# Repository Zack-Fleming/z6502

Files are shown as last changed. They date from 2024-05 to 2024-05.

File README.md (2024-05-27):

#Z6502

This is a collection of PCBs for a 6502-based computer. The core design of the computer is based on Ben Eater's design [here](https://eater.net/6502). I will be implementing changed to the original changes in the form of version revisions. Each board revision will have its own in-depth README.md, that will go over the changes in more depth and provide other relevant information.

This project was made using the KiCAD software, that can be downloaded [here](https://www.kicad.org/download/). If you do not have KiCAD, then there is also a zip file of the Gerber and Drill files needed to order a PCB. This zip file can be uploaded to any PCB manufacturer with no problem. 

Below the use of pinheaders is mentioned on different occasions, all of these pinheaders are of the 2.54mm pitch variety, and are the same used in the Arduino or Raspberry Pi boards as well. 

## Project Use

Use of this project is encouraged, as this is 'open-source'. I just ask to give credit to this project. 

I would like to know what others create for this project. 

## Revisions at a Glance

Revision V1:

The main changes of this version are the addition of data and control bus readouts, in the form of LEDs and pinheaders. Another change was to add PCB footprins for DIP-8 and DIP-14 type oscillators.

Currently planed Revisions:
- v2: adding a clock switching, clock dividing, halt switch, and power switch
- v3: adding another VIA chip (adding two more I/O ports)
- v4: removing the bus readouts, for miniaturization

## Modules

The computer features two 8-bit ports, that have their own headers for I/O modules. The silkscreen of the board will include all of the information for the design of the modules. This information includes: the position and size of the mounting holes, the length and width of the boards, and the position of the interface pin header. Both I/O ports are situated next to each other, and are identical in dimensions. If an I/O device needs to use both of the available ports, then one can just design a board that combines the two ports into a single board. There is no need to keep the device to only one port. 

I am currently working on a template project for KiCAD, where you can create a project from the template, instead of copy pasting the project multiple times.

Currently planed modules include:
- 1602A 16x2 character LCD screen
- 8x8 button matrix 'keyboard'
- clock switching (not an I/O module)
- LED matrix ??x??
- more.

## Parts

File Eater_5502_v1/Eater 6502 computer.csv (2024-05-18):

Id | Designator | Footprint | Quantity | Designation | Supplier and ref
1 | J5 | PinHeader_1x08_P2.54mm_Vertical | 1 | DATA_CONN
2 | C12,C11,C7,C9,C8,C10 | C_Disc_D5.0mm_W2.5mm_P2.50mm | 6 | 100n
3 | Y1 | Crystal_HC49-4H_Vertical | 1 | 1.84Mhz
4 | R13,R18,R33,R30,R24,R26,R16,R28,R8,R31,R19,R22,R14,R34,R21,R25,R11,R17,R20,R15,R23,R29,R12,R7,R5,R6,R4,R10,R32,R27,R9 | R_Axial_DIN0207_L6.3mm_D2.5mm_P2.54mm_Vertical | 31 | R
5 | U7 | DIP-14_W7.62mm_Socket_LongPads | 1 | 74HC00
6 | D5,D32,D27,D15,D26,D33,D4,D7,D25,D31,D18,D19,D24,D8,D28,D11,D10,D20,D12,D14,D9,D13,D30,D6,D29,D22,D3,D17,D16,D23,D21 | LED_D5.0mm | 31 | LED
7 | J6 | PinHeader_1x04_P2.54mm_Vertical | 1 | CPU_CONN
8 | R1,R2 | R_Axial_DIN0207_L6.3mm_D2.5mm_P2.54mm_Vertical | 2 | 1k
9 | C1 | C_Disc_D5.0mm_W2.5mm_P2.50mm | 1 | .1uF
10 | D2,D1 | D_DO-41_SOD81_P10.16mm_Horizontal | 2 | SB140
11 | U4 | DIP-40_W15.24mm_Socket_LongPads | 1 | WD65C02
12 | X2 | Oscillator_DIP-8 | 1 | 1-14mHz
13 | J4 | PinHeader_1x08_P2.54mm_Vertical | 1 | ADDR_LOW
14 | SW1 | SW_PUSH_6mm | 1 | RESET
15 | C6,C5,C3,C4 | C_Disc_D5.0mm_W2.5mm_P2.50mm | 4 | 1uF
16 | U3 | DIP-16_W7.62mm_Socket_LongPads | 1 | MAX232
17 | U1 | DIP-28_W15.24mm_Socket_LongPads | 1 | 28C256
18 | J1 | DSUB-9_Female_Horizontal_P2.77x2.84mm_EdgePinOffset9.90mm_Housed_MountingHolesOffset11.32mm | 1 | DE9_Plug
19 | U5 | DIP-28_W15.24mm_Socket_LongPads | 1 | W65C51N
20 | J7 | PinHeader_1x03_P2.54mm_Vertical | 1 | CS_CONN
21 | U2 | DIP-28_W15.24mm_Socket_LongPads | 1 | HM62256B
22 | J9 | PinHeader_1x08_P2.54mm_Vertical | 1 | ADDR_HIGH
23 | J8 | BarrelJack_GCT_DCJ200-10-A_Horizontal | 1 | PWR_IN
24 | J3 | PinHeader_1x10_P2.54mm_Vertical | 1 | PB_CONN
25 | R3 | R_Axial_DIN0207_L6.3mm_D2.5mm_P2.54mm_Vertical | 1 | 1M
26 | X1 | Oscillator_DIP-14 | 1 | 1-14mHz
27 | C2 | C_Disc_D5.0mm_W2.5mm_P5.00mm | 1 | 20p
28 | U6 | DIP-40_W15.24mm_Socket_LongPads | 1 | W65C22S
29 | J2 | PinHeader_1x10_P2.54mm_Vertical | 1 | PA_CONN

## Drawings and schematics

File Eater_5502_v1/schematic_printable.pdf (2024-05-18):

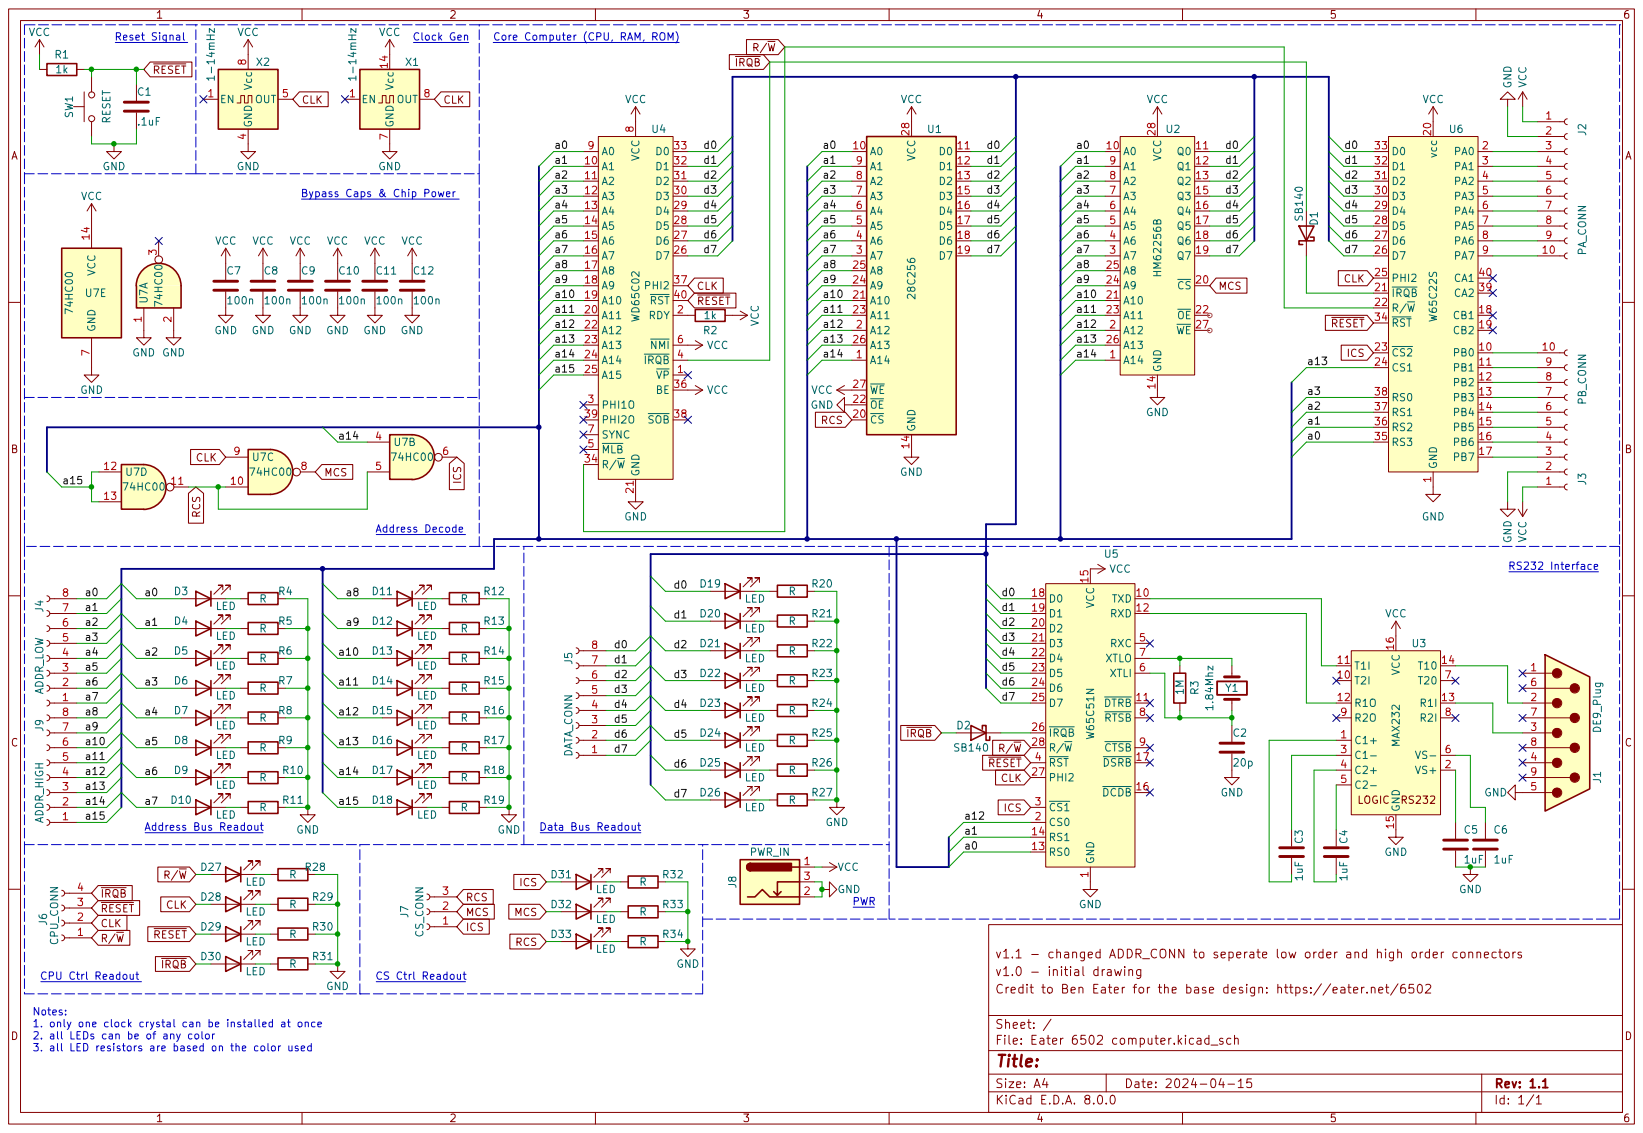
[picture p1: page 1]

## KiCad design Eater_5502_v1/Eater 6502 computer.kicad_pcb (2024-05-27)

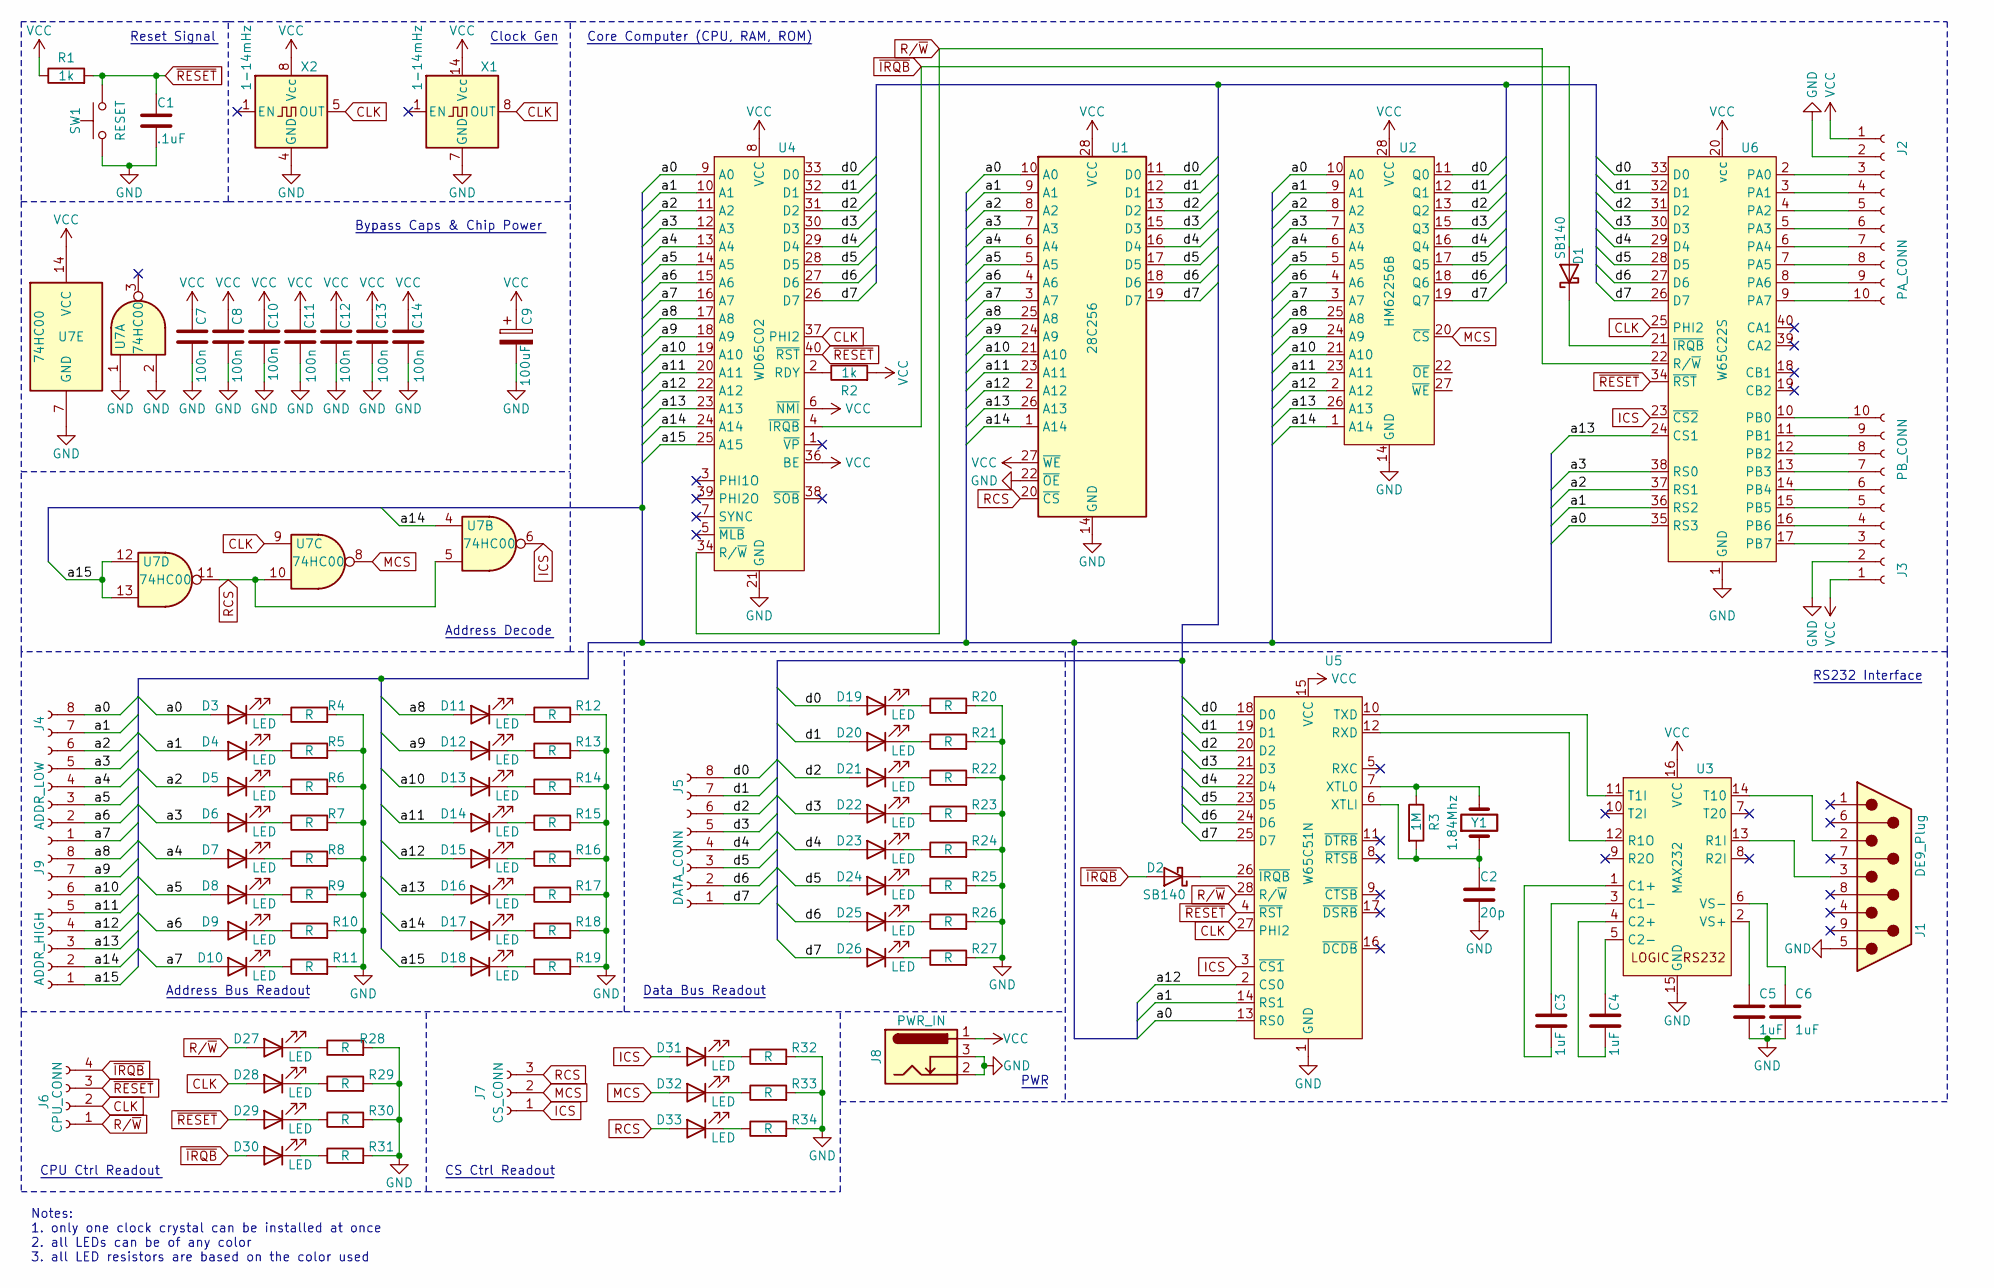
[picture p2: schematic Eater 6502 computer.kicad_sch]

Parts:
C1: .1uF; C_Disc_D5.0mm_W2.5mm_P5.00mm
C2: 20p; C_Disc_D5.0mm_W2.5mm_P5.00mm
C3, C4, C5, C6: 1uF; C_Disc_D5.0mm_W2.5mm_P5.00mm
C7, C8, C10, C11, C12, C13, C14: 100n; C_Disc_D5.0mm_W2.5mm_P5.00mm
C9: 100uF; CP_Radial_D5.0mm_P2.00mm
D1, D2: SB140; D_DO-41_SOD81_P10.16mm_Horizontal
D3, D4, D5, D6, D7, D8, D9, D10, D11, D12, D13, D14, D15, D16, D17, D18, D19, D20, D21, D22, D23, D24, D25, D26, D27, D28, D29, D30, D31, D32, D33: LED; LED_D5.0mm
J1: DE9_Plug; DSUB-9_Female_Horizontal_P2.77x2.84mm_EdgePinOffset9.90mm_H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
J2: PA_CONN; PinHeader_1x10_P2.54mm_Vertical
J3: PB_CONN; PinHeader_1x10_P2.54mm_Vertical
J4: ADDR_LOW; PinHeader_1x08_P2.54mm_Vertical
J5: DATA_CONN; PinHeader_1x08_P2.54mm_Vertical
J6: CPU_CONN; PinHeader_1x04_P2.54mm_Vertical
J7: CS_CONN; PinHeader_1x03_P2.54mm_Vertical
J8: PWR_IN; BarrelJack_GCT_DCJ200-10-A_Horizontal
J9: ADDR_HIGH; PinHeader_1x08_P2.54mm_Vertical
R1, R2: 1k; R_Axial_DIN0207_L6.3mm_D2.5mm_P2.54mm_Vertical
R3: 1M; R_Axial_DIN0207_L6.3mm_D2.5mm_P2.54mm_Vertical
R4, R5, R6, R7, R8, R9, R10, R11, R12, R13, R14, R15, R16, R17, R18, R19, R20, R21, R22, R23, R24, R25, R26, R27, R28, R29, R30, R31, R32, R33, R34: R; R_Axial_DIN0207_L6.3mm_D2.5mm_P2.54mm_Vertical
SW1: RESET; SW_PUSH_6mm
U1: 28C256; DIP-28_W15.24mm_Socket_LongPads
U2: HM62256B; DIP-28_W15.24mm_Socket_LongPads
U3: MAX232; DIP-16_W7.62mm_Socket_LongPads
U4: WD65C02; DIP-40_W15.24mm_Socket_LongPads
U5: W65C51N; DIP-28_W15.24mm_Socket_LongPads
U6: W65C22S; DIP-40_W15.24mm_Socket_LongPads
U7: 74HC00; DIP-14_W7.62mm_Socket_LongPads
X1: 1-14mHz; Oscillator_DIP-14
X2: 1-14mHz; Oscillator_DIP-8
Y1: 1.84Mhz; Crystal_HC49-4H_Vertical

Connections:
/a0: D3.2 (A), J4.8, U1.10 (A0), U2.10 (A0), U4.9 (A0), U5.13 (RS0), U6.35 (RS3)
/a1: D4.2 (A), J4.7, U1.9 (A1), U2.9 (A1), U4.10 (A1), U5.14 (RS1), U6.36 (RS2)
/a2: D5.2 (A), J4.6, U1.8 (A2), U2.8 (A2), U4.11 (A2), U6.37 (RS1)
/a3: D6.2 (A), J4.5, U1.7 (A3), U2.7 (A3), U4.12 (A3), U6.38 (RS0)
/a4: D7.2 (A), J4.4, U1.6 (A4), U2.6 (A4), U4.13 (A4)
/a5: D8.2 (A), J4.3, U1.5 (A5), U2.5 (A5), U4.14 (A5)
/a6: D9.2 (A), J4.2, U1.4 (A6), U2.4 (A6), U4.15 (A6)
/a7: D10.2 (A), J4.1, U1.3 (A7), U2.3 (A7), U4.16 (A7)
/a8: D11.2 (A), J9.8, U1.25 (A8), U2.25 (A8), U4.17 (A8)
/a9: D12.2 (A), J9.7, U1.24 (A9), U2.24 (A9), U4.18 (A9)
/a10: D13.2 (A), J9.6, U1.21 (A10), U2.21 (A10), U4.19 (A10)
/a11: D14.2 (A), J9.5, U1.23 (A11), U2.23 (A11), U4.20 (A11)
/a12: D15.2 (A), J9.4, U1.2 (A12), U2.2 (A12), U4.22 (A12), U5.2 (CS0)
/a13: D16.2 (A), J9.3, U1.26 (A13), U2.26 (A13), U4.23 (A13), U6.24 (CS1)
/a14: D17.2 (A), J9.2, U1.1 (A14), U2.1 (A14), U4.24 (A14), U7.4
/a15: D18.2 (A), J9.1, U4.25 (A15), U7.12, U7.13
/d0: D19.2 (A), J5.8, U1.11 (D0), U2.11 (Q0), U4.33 (D0), U5.18 (D0), U6.33 (D0)
/d1: D20.2 (A), J5.7, U1.12 (D1), U2.12 (Q1), U4.32 (D1), U5.19 (D1), U6.32 (D1)
/d2: D21.2 (A), J5.6, U1.13 (D2), U2.13 (Q2), U4.31 (D2), U5.20 (D2), U6.31 (D2)
/d3: D22.2 (A), J5.5, U1.15 (D3), U2.15 (Q3), U4.30 (D3), U5.21 (D3), U6.30 (D3)
/d4: D23.2 (A), J5.4, U1.16 (D4), U2.16 (Q4), U4.29 (D4), U5.22 (D4), U6.29 (D4)
/d5: D24.2 (A), J5.3, U1.17 (D5), U2.17 (Q5), U4.28 (D5), U5.23 (D5), U6.28 (D5)
/d6: D25.2 (A), J5.2, U1.18 (D6), U2.18 (Q6), U4.27 (D6), U5.24 (D6), U6.27 (D6)
/d7: D26.2 (A), J5.1, U1.19 (D7), U2.19 (Q7), U4.26 (D7), U5.25 (D7), U6.26 (D7)
CLK: D28.2 (A), J6.2, U4.37 (PHI2), U5.27 (PHI2), U6.25 (PHI2), U7.9, X1.8 (OUT), X2.5 (OUT)
GND: C1.2, C2.2, C5.2, C6.2, C7.2, C8.2, C9.2, C10.2, C11.2, C12.2, C13.2, C14.2, J1.0, J1.5, J2.2, J3.2, J8.2, J8.3, R4.2, R5.2, R6.2, R7.2, R8.2, R9.2, R10.2, R11.2, R12.2, R13.2, R14.2, R15.2, R16.2, R17.2, R18.2, R19.2, R20.2, R21.2, R22.2, R23.2, R24.2, R25.2, R26.2, R27.2, R28.2, R29.2, R30.2, R31.2, R32.2, R33.2, R34.2, SW1.1, U1.14 (GND), U1.22 (~OE), U2.14 (GND), U3.15 (GND), U4.21 (GND), U5.1 (GND), U6.1 (GND), U7.1, U7.2, U7.7 (GND), X1.7 (GND), X2.4 (GND)
ICS: D31.2 (A), J7.1, U5.3 (~CS1), U6.23 (~CS2), U7.6
MCS: D32.2 (A), J7.2, U2.20 (~CS), U7.8
unnamed: D1.1 (K), U6.21 (~IRQB)
unnamed: D2.1 (K), U5.26 (~IRQB)
unnamed: D3.1 (K), R4.1
unnamed: D4.1 (K), R5.1
unnamed: D5.1 (K), R6.1
unnamed: D6.1 (K), R7.1
unnamed: D7.1 (K), R8.1
unnamed: D8.1 (K), R9.1
unnamed: D9.1 (K), R10.1
unnamed: D10.1 (K), R11.1
unnamed: D11.1 (K), R12.1
unnamed: D12.1 (K), R13.1
unnamed: D13.1 (K), R14.1
unnamed: D14.1 (K), R15.1
unnamed: D15.1 (K), R16.1
unnamed: D16.1 (K), R17.1
unnamed: D17.1 (K), R18.1
unnamed: D18.1 (K), R19.1
unnamed: D19.1 (K), R20.1
unnamed: D20.1 (K), R21.1
unnamed: D21.1 (K), R22.1
unnamed: D22.1 (K), R23.1
unnamed: D23.1 (K), R24.1
unnamed: D24.1 (K), R25.1
unnamed: D25.1 (K), R26.1
unnamed: D26.1 (K), R27.1
unnamed: D27.1 (K), R28.1
unnamed: D28.1 (K), R29.1
unnamed: D29.1 (K), R30.1
unnamed: D30.1 (K), R31.1
unnamed: D31.1 (K), R32.1
unnamed: D32.1 (K), R33.1
unnamed: D33.1 (K), R34.1
unnamed: J2.3, U6.2 (PA0)
unnamed: J2.4, U6.3 (PA1)
unnamed: J2.5, U6.4 (PA2)
unnamed: J2.6, U6.5 (PA3)
unnamed: J2.7, U6.6 (PA4)
unnamed: J2.8, U6.7 (PA5)
unnamed: J2.9, U6.8 (PA6)
unnamed: J2.10, U6.9 (PA7)
unnamed: J3.3, U6.17 (PB7)
unnamed: J3.4, U6.16 (PB6)
unnamed: J3.5, U6.15 (PB5)
unnamed: J3.6, U6.14 (PB4)
unnamed: J3.7, U6.13 (PB3)
unnamed: J3.8, U6.12 (PB2)
unnamed: J3.9, U6.11 (PB1)
unnamed: J3.10, U6.10 (PB0)
unnamed: C3.2, U3.1 (C1+)
unnamed: C3.1, U3.3 (C1-)
unnamed: C4.2, U3.4 (C2+)
unnamed: C4.1, U3.5 (C2-)
unnamed: J1.3, U3.13 (R1I)
unnamed: U3.12 (R1O), U5.12 (RXD)
unnamed: U3.11 (T1I), U5.10 (TXD)
unnamed: J1.2, U3.14 (T10)
unnamed: C5.1, U3.2 (VS+)
unnamed: C6.1, U3.6 (VS-)
unnamed: R2.1, U4.2 (RDY)
unnamed: C2.1, R3.2, U5.6 (XTLI), Y1.1
unnamed: R3.1, U5.7 (XTLO), Y1.2
RCS: D33.2 (A), J7.3, U1.20 (~CS), U7.5, U7.10, U7.11
R/~W: D27.2 (A), J6.1, U4.34 (R/~W), U5.28 (R/~W), U6.22 (R/~W)
VCC: C7.1, C8.1, C9.1, C10.1, C11.1, C12.1, C13.1, C14.1, J2.1, J3.1, J8.1, R1.1, R2.2, U1.27 (~WE), U1.28 (VCC), U2.28 (VCC), U3.16 (VCC), U4.6 (~NMI), U4.8 (VCC), U4.36 (BE), U5.15 (VCC), U6.20 (vcc), U7.14 (VCC), X1.14 (Vcc), X2.8 (Vcc)
~IRQB: D1.2 (A), D2.2 (A), D30.2 (A), J6.4, U4.4 (~IRQB)
~RESET: C1.1, D29.2 (A), J6.3, R1.2, SW1.2, U4.40 (~RST), U5.4 (~RST), U6.34 (~RST)

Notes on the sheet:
Address Decode ~{ }
CPU Ctrl Readout ~{ }
Notes: 1. only one clock crystal can be installed at once 2. all LEDs can be of any color 3. all LED resistors are based on the color used
Core Computer (CPU, RAM, ROM) ~{ }
Clock Gen ~{ }
Data Bus Readout ~{ }
RS232 Interface ~{ }
Reset Signal ~{ }
CS Ctrl Readout ~{ }
PWR ~{ }
Address Bus Readout ~{ }
Bypass Caps & Chip Power ~{ }

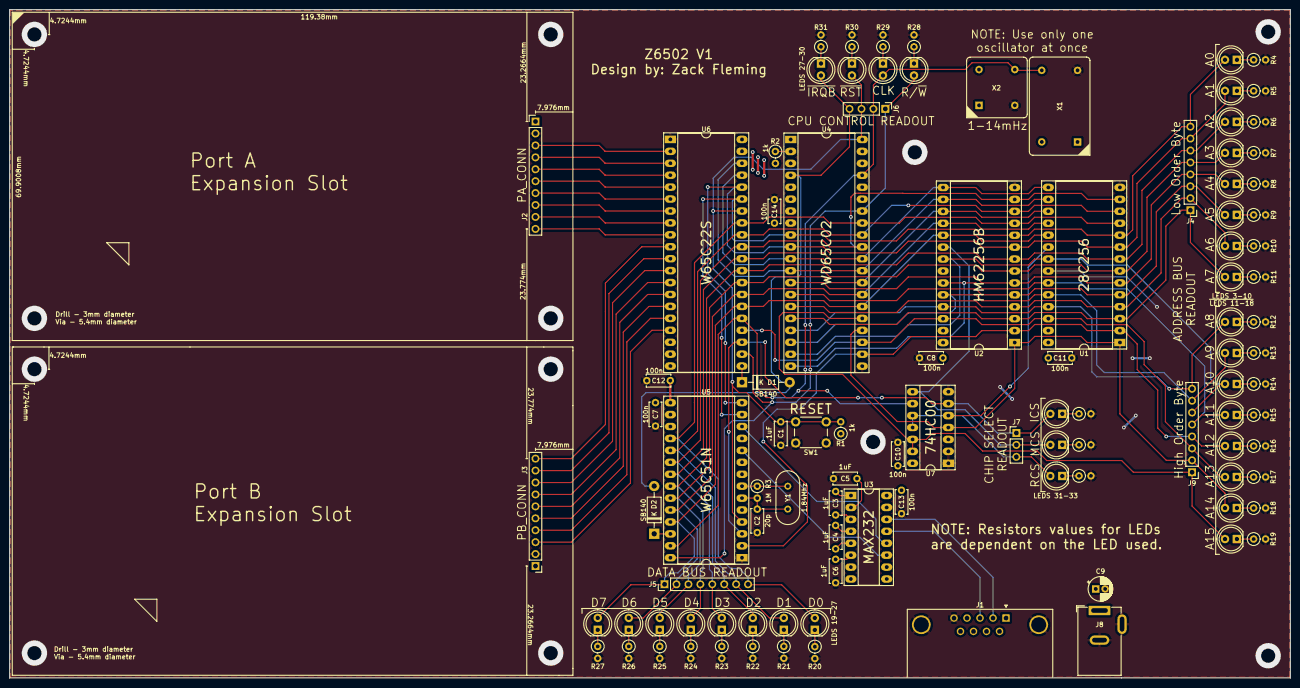
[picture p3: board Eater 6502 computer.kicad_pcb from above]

Board: 2 copper layers, 272.7 x 142.3 mm, 101 parts (0 on the bottom side), 95 nets.

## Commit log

2024-05-18 finish v1 of main board
    [Eater 6502 computer-B_Cu.gbr, Eater 6502 computer-B_Mask.gbr, Eater 6502 computer-B_Paste.gbr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]
2024-05-27 updated board design to include bigger capacitor footprints, added the bulk decoupling cap to the power input, and made text larger in places to improve readability
    [Eater 6502 computer-B_Cu.gbr, Eater 6502 computer-B_Mask.gbr, Eater 6502 computer-B_Paste.gbr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]
